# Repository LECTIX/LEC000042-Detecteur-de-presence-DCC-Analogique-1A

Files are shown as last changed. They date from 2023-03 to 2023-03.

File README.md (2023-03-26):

# LEC000042-Detecteur-de-presence-DCC-Analogique-1A
Fichiers sources pour le produit LEC000042

## Description du produit

### DCC (Digital)

En DCC, le détecteur d’occupation LEC000042 permet de détecter l’occupation d’un tronçon de voie et de déclencher de nombreux automatismes ou systèmes.
- Détecte tous les trains dans les **2 sens de marche**.
- Seuil de détection **ultrasensible et réglable**.
- **Relais double inverseur** pour y brancher n'importe quel système.
- Temporisation à la désactivation pour **éviter des réactivations intempestives**.
- **Possibilité de forcer** l'activation du relais via un bornier dédié.

### Analogique

Le détecteur d’occupation LEC000042 permet de détecter l’occupation d’un tronçon de voie et de déclencher de nombreux automatismes ou systèmes.
- Détecte tous les trains dans **1 seul sens de marche, à partir de 6 V**.
- Seuil de détection **ultrasensible et réglable**.
- **Relais double inverseur** pour y brancher n'importe quel système.
- Temporisation à la désactivation pour **éviter des réactivations intempestives**.
- **Possibilité de forcer** l'activation du relais via un bornier dédié.

## Utiliser les fichiers sources pour fabriquer le produit

Il n'est **pas nécessaire de savoir souder ou d'être bon en électronique** pour se procurer ce produit. Grâce aux fichiers sources publiés ici, vous pouvez être en mesure de faire fabriquer ce produit par un sous traitant.

### Faire fabriquer chez un sous traitant

Il est aujourd'hui possible de faire fabriquer à moindre cout des cartes électroniques. Nous recommendons [JLCPCB](https://jlcpcb.com/) si vous voulez aller au moins cher. Si vous préférez un acteur européen, [eurocircuits](https://www.eurocircuits.com/) est un des acteurs reconnus.

IMAGE ALT TEXT (http://www.youtube.com/watch?v=RXGGvsUtz0c "TUTO : faire fabriquer un produit LECTIX")

1. Télécherger les sources de ce produit en cliquant sur le bouton `Code`, puis `Download ZIP`.
1. Décompresser le dossier.
1. Les fichiers pour la fabrication se trouvent dans le répertoire `hardware/prod`.
1. Se connecter sur [https://cart.jlcpcb.com/quote](https://cart.jlcpcb.com/quote)
1. Cliquer sur le bouton `Add gerber file` et sélectionner le fichier `gerbers.zip`.
1. Sélectionnez la quantité de cartes que vous souhaitez dans le champs `PCB Qty`.
1. Laisser toutes les autres options par défaut, puis cliquez sur le toggle switch en face de `PCB Assembly`, et enfin sur le bouton `confirm`.
1. Une preview de la carte électronique sans les composants doit apparaitre. Cliquez sur `NEXT`.
1. Cliquez sur le bouton `Add BOM File`, puis sélectionnez le fichier `bom.csv`
1. Cliquez sur le bouton `Add CPL File`, puis sélectionnez le fichier `pos.csv`
1. **Vérifier que tous les composants sont en stock** et bien sélectionnés, puis cliquez sur `NEXT`.
1. Une preview de la carte avec ses composants apparait. Continuer le chemin en cliquant sur `NEXT`.
1. Le prix final apparait. Sélectionnez la catégorie du produit, puis cliquez sur `SAVE TO CART`.
1. Une fois sauvegardé dans votre panier, vous pouvez valider votre commande et choisir le moyen d'acheminement. Afin de ne pas avoir à se préoccuper des frais de douane, nous vous conseillons de choisir une méthode d'expédition DDP.

Vous receverez vos cartes sous 1 à 3 semaines. 

**Nous ne sommes en aucun cas responsables des cartes qui arriveraient défectueuses ou non fonctionnelles.**

### Modifications des fichiers sources

Installez kicad 6 (ou version supérieure), et ouvrez le fichier LEC000042.kicad_pro

### Regénérer les fichiers gerber, BOM, et position (Optionnel)

Peut se faire simplement en utilisant kikit :

```
cd hardware
docker run --rm -w /kikit -v $PWD:/kikit yaqwsx/kikit kikit fab jlcpcb --assembly --no-drc --schematic LEC000042.kicad_sch --field LCSC --corrections JLCPCB_CORRECTION --nametemplate LEC000042_{} LEC000042.kicad_pcb prod/

```
## Notices

### DCC

[Manuel FR](docs/dcc/manual_fr.pdf)

[Manuel EN](docs/dcc/manual_en.pdf)

### Analogique

[Manuel FR](docs/analogique/manual_fr.pdf)

## License
Tous nos fichiers sont plubliés sous la license CERN Open Hardware Licence Version 2 - Strongly Reciprocal

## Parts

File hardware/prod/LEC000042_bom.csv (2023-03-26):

Comment | Designator | Footprint | LCSC
100uF | C1,C3 | 0_capacitors:CP_Elec_6.3x5.8 | C249982
100nF | C2,C5 | Capacitor_SMD:C_0603_1608Metric | C14663
10n | C6 | Capacitor_SMD:C_0603_1608Metric | C57112
10uF | C7,C8 | Capacitor_Tantalum_SMD:CP_EIA-3216-18_Kemet-A | C7171
MB10S | D1 | Package_TO_SOT_SMD:TO-269AA | C2488
D | D2,D3,D4,D5,D8,D9 | Diode_SMD:D_SMA | C95872
D_Schottky_Small | D6 | Diode_SMD:D_SMA | C22452
LED | D7 | LED_SMD:LED_0603_1608Metric | C72043
FORCE_ACTIVATION | J1 | 0_connectors:TerminalBlock_bornier-2_P5.08mm-blue | C430621
TRACKS_OUT | J2 | 0_connectors:TerminalBlock_bornier-2_P5.08mm-blue | C430621
TRACKS_IN | J3 | 0_connectors:TerminalBlock_bornier-2_P5.08mm-green | C395849
CONTACT_1 | J5 | 0_connectors:TerminalBlock_bornier-3_P5.08mm-blue | C430620
CONTACT_2 | J6 | 0_connectors:TerminalBlock_bornier-3_P5.08mm-blue | C430620
HK19F-5V | K1 | 0_relays:Relay_DPDT_HK19F | C54512
47uH | L1 | Inductor_SMD:L_12x12mm_H6mm | C169398
S8050 | Q1 | Package_TO_SOT_SMD:SOT-23 | C2146
27 | R1 | Resistor_SMD:R_0603_1608Metric | C25190
3k | R2 | Resistor_SMD:R_0603_1608Metric | C4211
1k | R3,R5,R6 | Resistor_SMD:R_0603_1608Metric | C21190
180k | R4 | Resistor_SMD:R_0603_1608Metric | C22827
10k | R7 | Resistor_SMD:R_0603_1608Metric | C25804
500k | RV1 | 0_potentiometers:BOURNS-3362P_pot | C125021
NE555 | U1 | Package_SO:SOIC-8_3.9x4.9mm_P1.27mm | C7593
CYPC817 | U2 | Package_DIP:SMDIP-4_W9.53mm_Clearance8mm | C385060
XL1509-ADJE1 | U3 | Package_SO:SOP-8_3.76x4.96mm_P1.27mm | C74192

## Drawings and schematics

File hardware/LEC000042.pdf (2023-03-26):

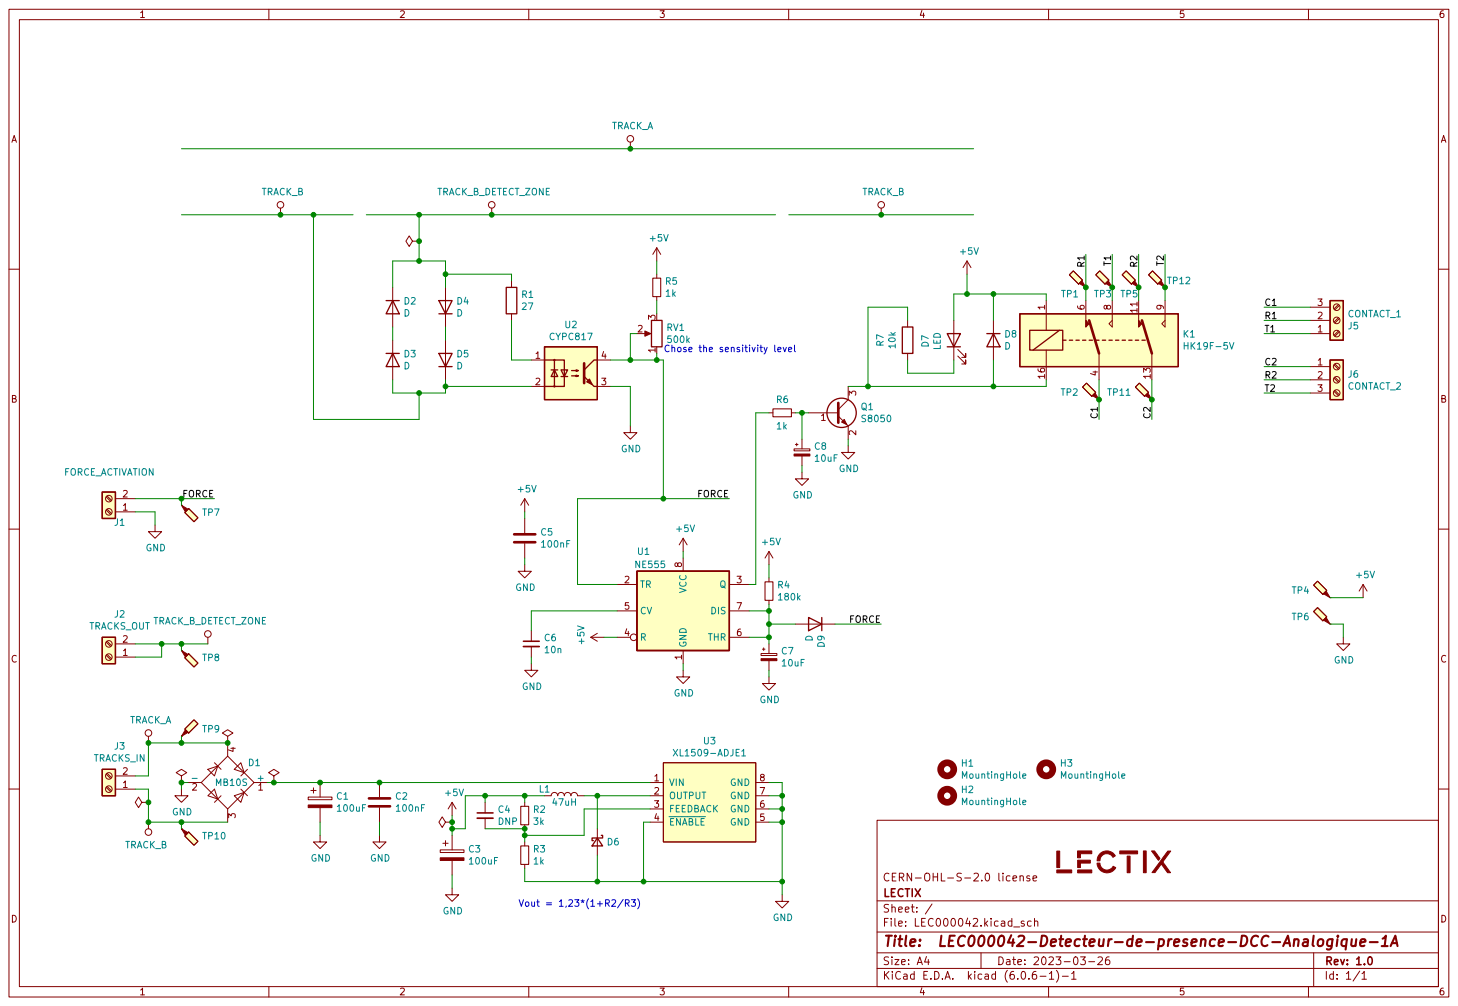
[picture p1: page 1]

9 K1HK19F-5V D6 VIN 1 OUTPUT 2 FEEDBACK 3 ~{ENABLE} 4 GND 5 GND 6 GND 7 GND 8 U3 XL1509-ADJE1 R2

File: LEC000042.kicad_sch Sheet: / LECTIX CERN-OHL-S-2.0 license

Id: 1/1 Title: LEC000042-Detecteur-de-presence-DCC-Analogique-1A

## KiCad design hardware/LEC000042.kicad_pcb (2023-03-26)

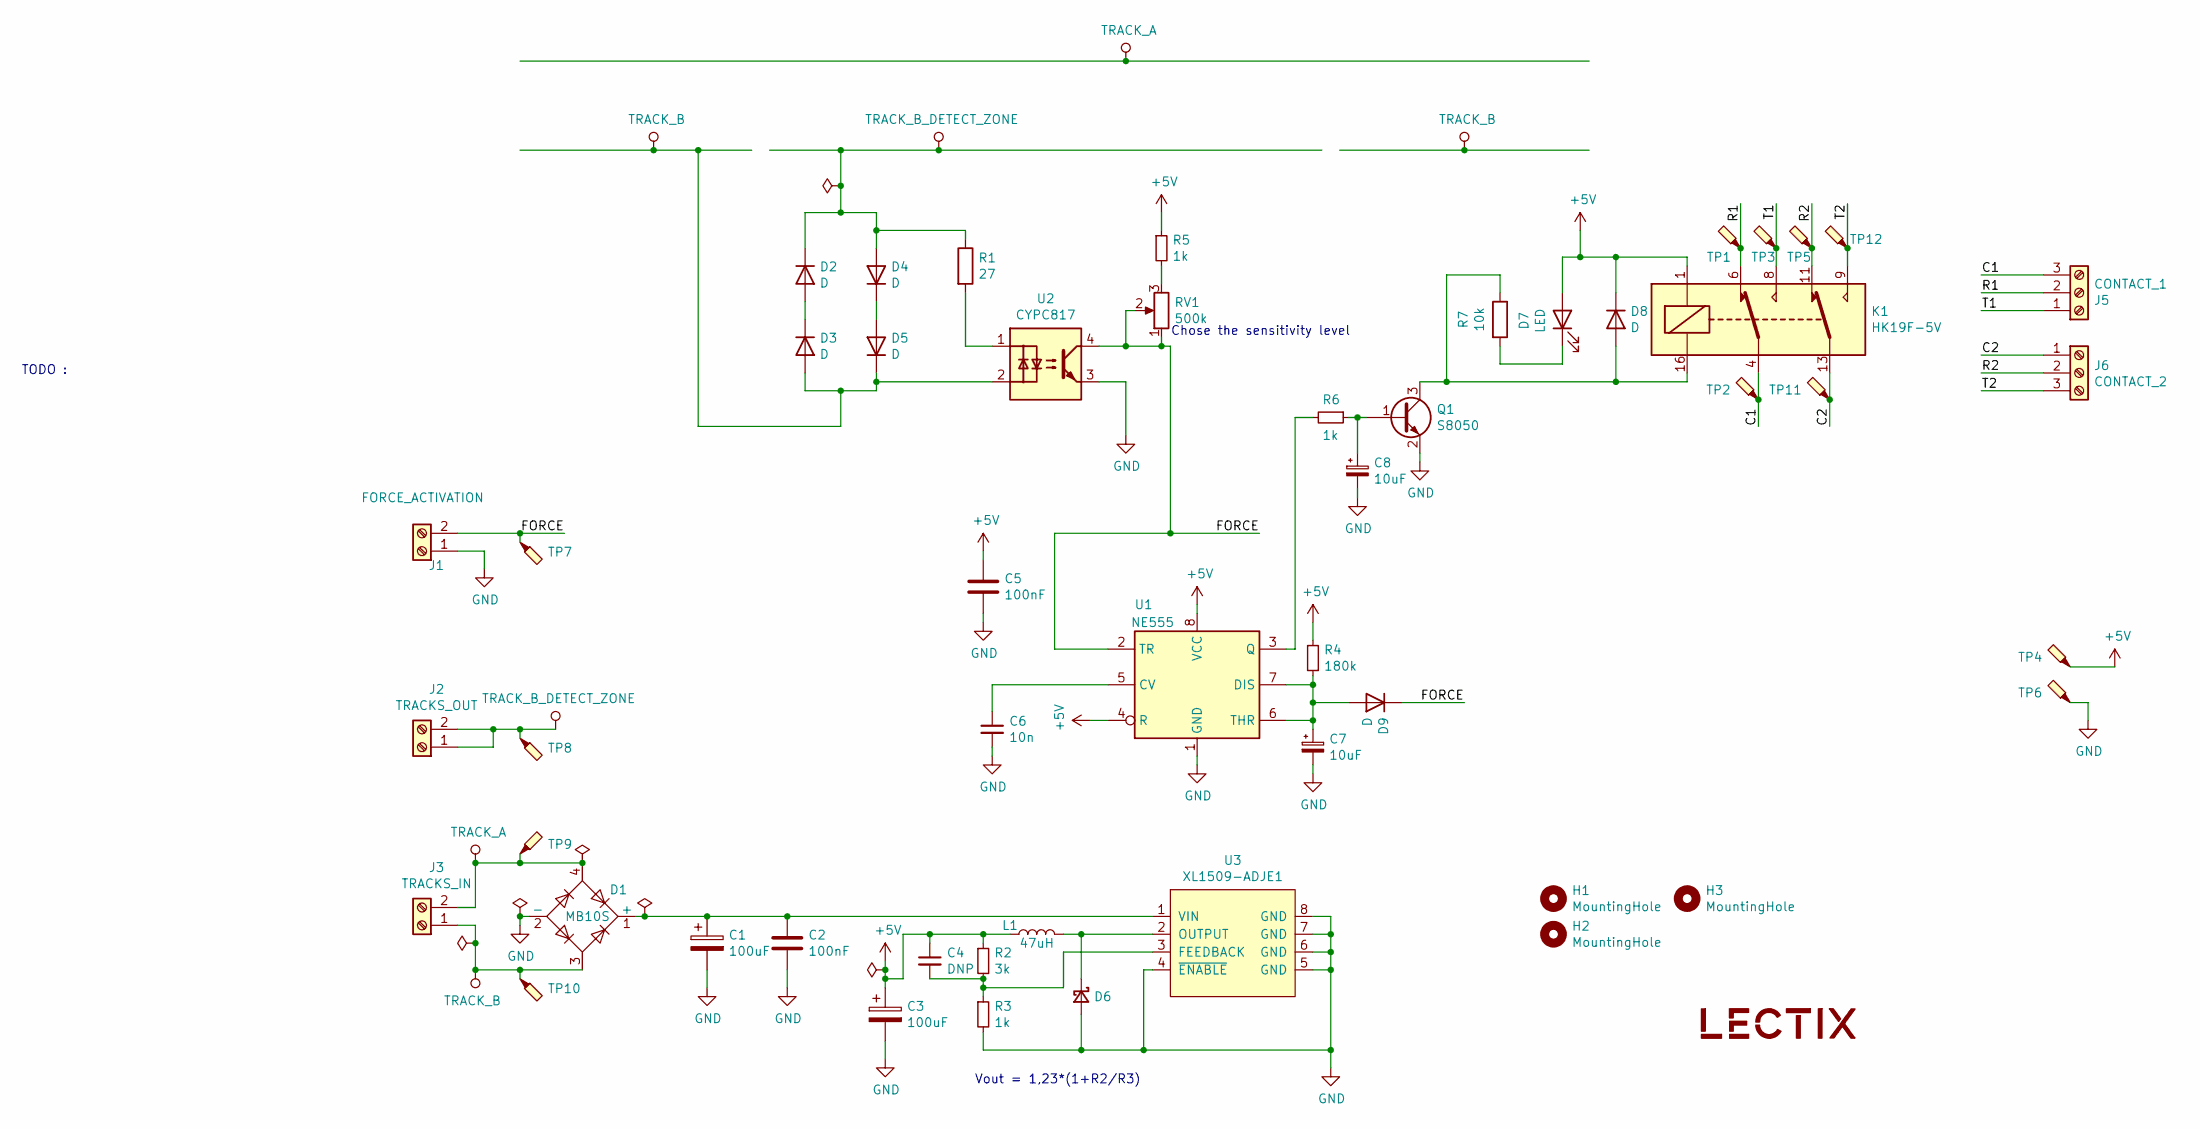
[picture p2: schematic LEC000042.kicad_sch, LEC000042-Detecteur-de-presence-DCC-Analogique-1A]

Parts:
C1, C3: 100uF; CP_Elec_6.3x5.8; MPN VZT101M1VTR-0606; LCSC C249982
C2, C5: 100nF; C_0603_1608Metric; MPN CC0603KRX7R9BB104; LCSC C14663
C4: DNP; C_0603_1608Metric; MPN DNP; LCSC DNP
C6: 10n; C_0603_1608Metric; MPN 0603B103K500NT; LCSC C57112
C7, C8: 10uF; CP_EIA-3216-18_Kemet-A; MPN TAJA106K016RNJ; LCSC C7171
D1: MB10S; TO-269AA; MPN MB10S; LCSC C2488
D2, D3, D4, D5, D8, D9: D; D_SMA; MPN M7; LCSC C95872
D6: D_Schottky_Small; D_SMA; MPN SS54; LCSC C22452
D7: LED; LED_0603_1608Metric; MPN 19-217/GHC-YR1S2/3T; LCSC C72043
H1, H2, H3: MountingHole; MountingHole_3.2mm_M3; MPN DNP; LCSC DNP
J1: FORCE_ACTIVATION; TerminalBlock_bornier-2_P5.08mm-blue; MPN DB301V-5.0-2P-BU-P; LCSC C430621
J2: TRACKS_OUT; TerminalBlock_bornier-2_P5.08mm-blue; MPN DB301V-5.0-2P-BU-P; LCSC C430621
J3: TRACKS_IN; TerminalBlock_bornier-2_P5.08mm-green; MPN DB126V-5.0-2P-GN; LCSC C395849
J5: CONTACT_1; TerminalBlock_bornier-3_P5.08mm-blue; MPN DB301V-5.0-3P-BU-P; LCSC C430620
J6: CONTACT_2; TerminalBlock_bornier-3_P5.08mm-blue; MPN DB301V-5.0-3P-BU-P; LCSC C430620
K1: HK19F-5V; Relay_DPDT_HK19F; MPN HK19F-DC5V-SHG-Y; LCSC C54512
L1: 47uH; L_12x12mm_H6mm; MPN SWRB1204S-470MT; LCSC C169398
LOGO1: logo_lectix_25mm; Logo_10mm; MPN DNP; LCSC DNP
Q1: S8050; SOT-23; MPN S8050; LCSC C2146
R1: 27; R_0603_1608Metric; MPN 0603WAF270JT5E; LCSC C25190
R2: 3k; R_0603_1608Metric; MPN 0603WAF3001T5E; LCSC C4211
R3, R5, R6: 1k; R_0603_1608Metric; MPN 0603WAF1001T5E; LCSC C21190
R4: 180k; R_0603_1608Metric; MPN 0603WAF1803T5E; LCSC C22827
R7: 10k; R_0603_1608Metric; MPN 0603WAF1002T5E; LCSC C25804
RV1: 500k; BOURNS-3362P_pot; MPN 3362P-1-504; LCSC C125021
TP1, TP2, TP3, TP4, TP5, TP6, TP7, TP8, TP9, TP10, TP11, TP12: TestPoint_Probe; TestPoint_Pad_D1.5mm; MPN DNP; LCSC DNP
U1: NE555; SOIC-8_3.9x4.9mm_P1.27mm; MPN NE555; LCSC C7593
U2: CYPC817; SMDIP-4_W9.53mm_Clearance8mm; MPN CYPC817(B-TP2); LCSC C385060
U3: XL1509-ADJE1; SOP-8_3.76x4.96mm_P1.27mm; MPN XL1509-ADJE1; LCSC C74192

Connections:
+5V: C3.1, C4.1, C5.1, D7.2 (A), D8.1 (K), K1.1, L1.1, R2.1, R4.1, R5.1, TP4.1, U1.4 (R), U1.8 (VCC)
/C1: J5.3, K1.4, TP2.1
/C2: J6.1, K1.13, TP11.1
/FORCE: D9.1 (K), J1.2, RV1.1, RV1.2, TP7.1, U1.2 (TR), U2.4
/R1: J5.2, K1.6, TP1.1
/R2: J6.2, K1.11, TP5.1
/T1: J5.1, K1.8, TP3.1
/T2: J6.3, K1.9, TP12.1
GND: C1.2, C2.2, C3.2, C5.2, C6.2, C7.2, C8.2, D1.2 (-), D6.2 (A), J1.1, Q1.2 (E), R3.2, TP6.1, U1.1 (GND), U2.3, U3.4 (~ENABLE), U3.5 (GND), U3.6 (GND), U3.7 (GND), U3.8 (GND)
unnamed: C1.1, C2.1, D1.1 (+), U3.1 (VIN)
unnamed: C4.2, R2.2, R3.1, U3.3 (FEEDBACK)
unnamed: C6.1, U1.5 (CV)
unnamed: C7.1, D9.2 (A), R4.2, U1.6 (THR), U1.7 (DIS)
unnamed: C8.1, Q1.1 (B), R6.1
unnamed: D2.2 (A), D3.1 (K)
unnamed: D4.1 (K), D5.2 (A)
unnamed: D6.1 (K), L1.2, U3.2 (OUTPUT)
unnamed: D7.1 (K), R7.2
unnamed: D8.2 (A), K1.16, Q1.3 (C), R7.1
unnamed: R1.2, U2.1
unnamed: R5.2, RV1.3
unnamed: R6.2, U1.3 (Q)
TRACK_A: D1.4, J3.2, TP9.1
TRACK_B: D1.3, D3.2 (A), D5.1 (K), J3.1, TP10.1, U2.2
TRACK_B_DETECT_ZONE: D2.1 (K), D4.2 (A), J2.1, J2.2, R1.1, TP8.1

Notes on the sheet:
TODO :
Vout = 1,23*(1+R2/R3)
Chose the sensitivity level

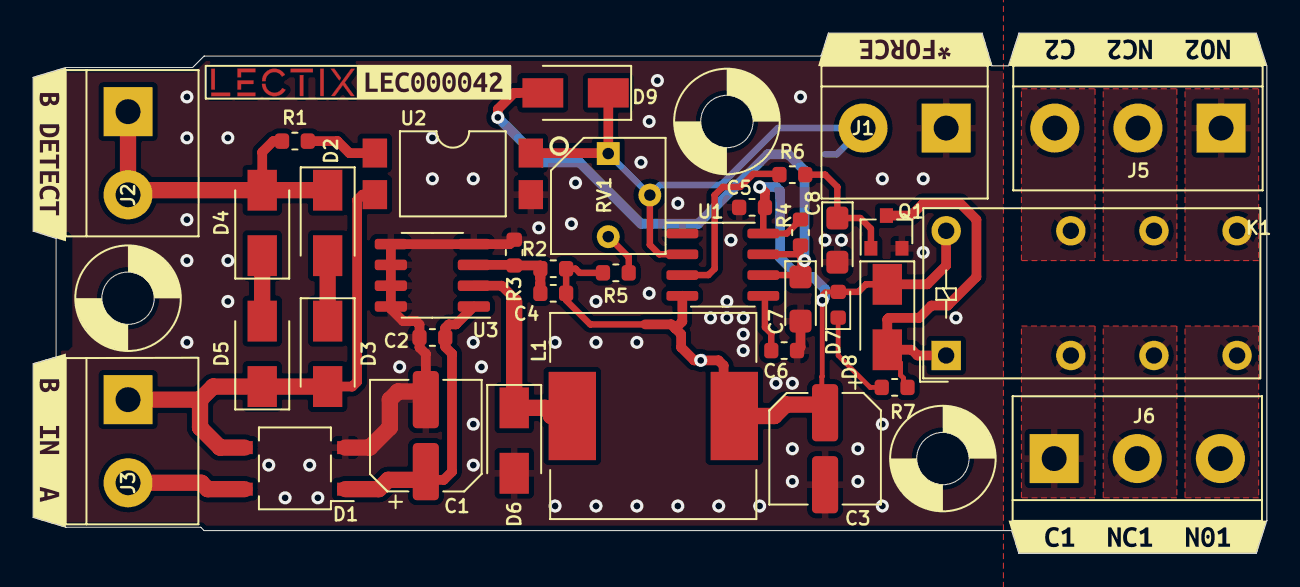
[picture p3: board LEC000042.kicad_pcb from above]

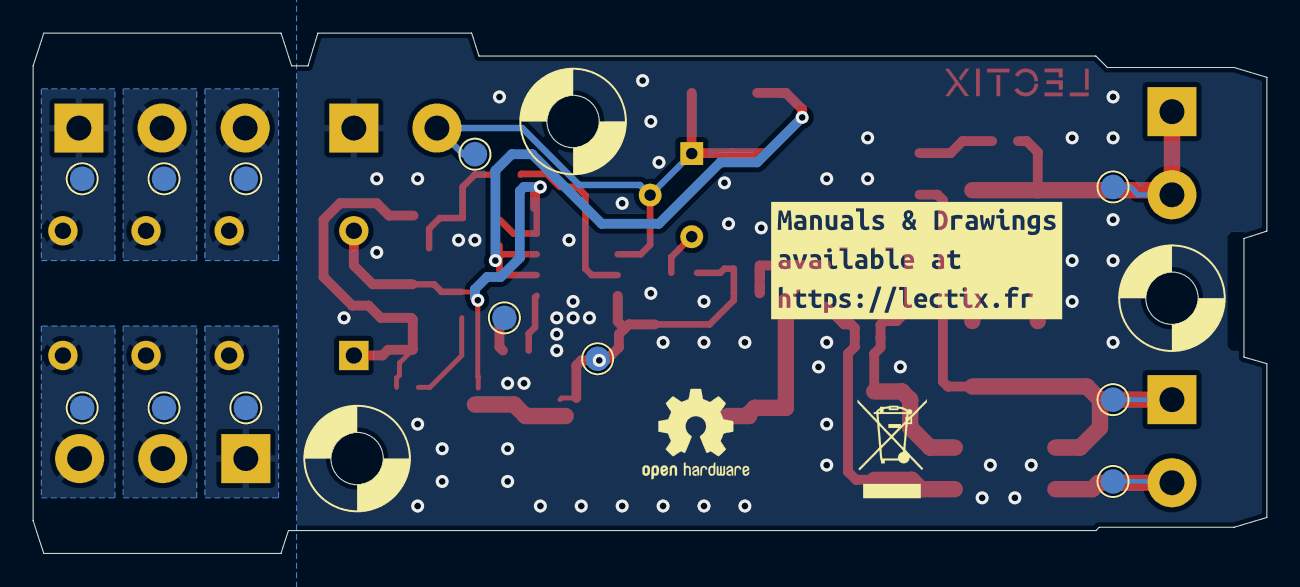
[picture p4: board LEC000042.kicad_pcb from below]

Board: 2 copper layers, 75.4 x 31.8 mm, 59 parts (13 on the bottom side), 25 nets.

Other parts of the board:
kibuzzard-624D4A0B: G***; kibuzzard-624D4A0B
kibuzzard-624D4A7D: G***; kibuzzard-624D4A7D
kibuzzard-624D4ACF: G***; kibuzzard-624D4ACF
kibuzzard-624D4AF8: G***; kibuzzard-624D4AF8
kibuzzard-624D4BCC: G***; kibuzzard-624D4BCC
kibuzzard-624D4BDE: G***; kibuzzard-624D4BDE
kibuzzard-624D5053: G***; kibuzzard-624D5053

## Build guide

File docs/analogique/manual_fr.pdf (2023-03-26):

# Détecteur d’occupation (Analogique)

### LEC000042

☞ Attention : ce manuel décrit l’utilisation du module LEC000042 pour une installation en analogique uniquement. Pour une utilisation en DCC, rendez vous sur notre site web. (https://lectix.fr/)

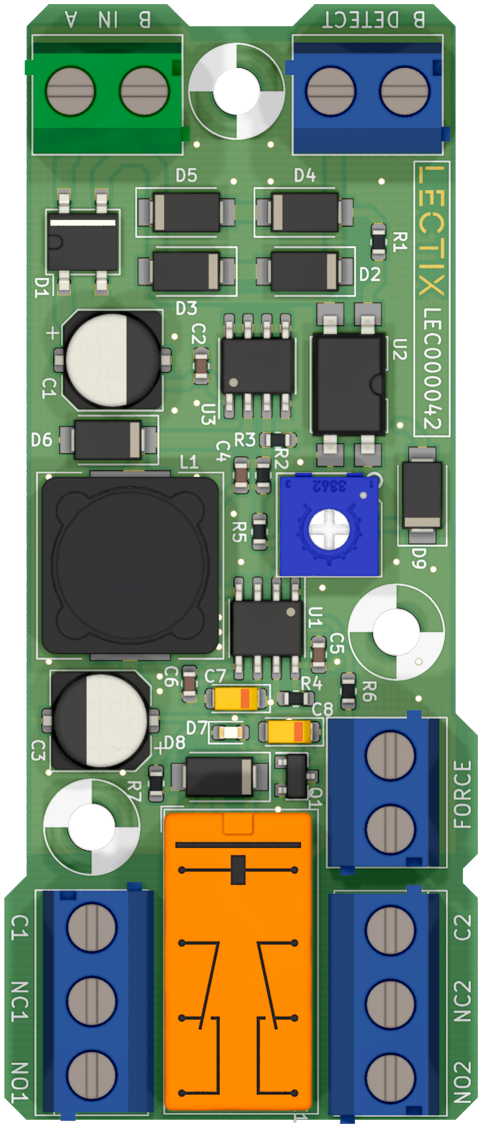
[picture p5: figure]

## 1 Caractéristiques

- Capable de détecter tous les trains dans 1 seul sens de marche, à partir de 6 V.
- Réglage possible du seuil de détection (de 0.2 mA à 2 mA).
- Possède un relais à 2 contacts inverseurs indépendants pour y brancher n’importe quel système.
- Témoin lumineux d’activation.
- Possibilité de forcer l’activation du module par un actionneur externe.
- Temporisation à la désactivation pour éviter des réactivations intempestives.

## 2 Applications

- Cantonnement.
- Déclenchement d’un bruitage.
- Automatismes (passage à niveau, ...).
- Gestion de la signalisation.

## 3 Specifications technique

Specification | Valeur | Unité
Seuil de détection | 0.2 - 2 | mA
Consommation (inactif @20V) (actif @20V) | 3.5 17 | mA mA
Pouvoir de coupure du relais | 1A 125V AC 2A 30V DC | -
Courant max supporté | 1 | A
Tension de fonctionnement | 6 à 20 | V DC

Table 1: Spécifications

LEC000042 - Détecteur d’occupation (Analogique) rev 4.2.1 | 1

## 4 Dimensions

Le module dispose de trois trous de fixation permettant de faire passer des vis de 3 mm.

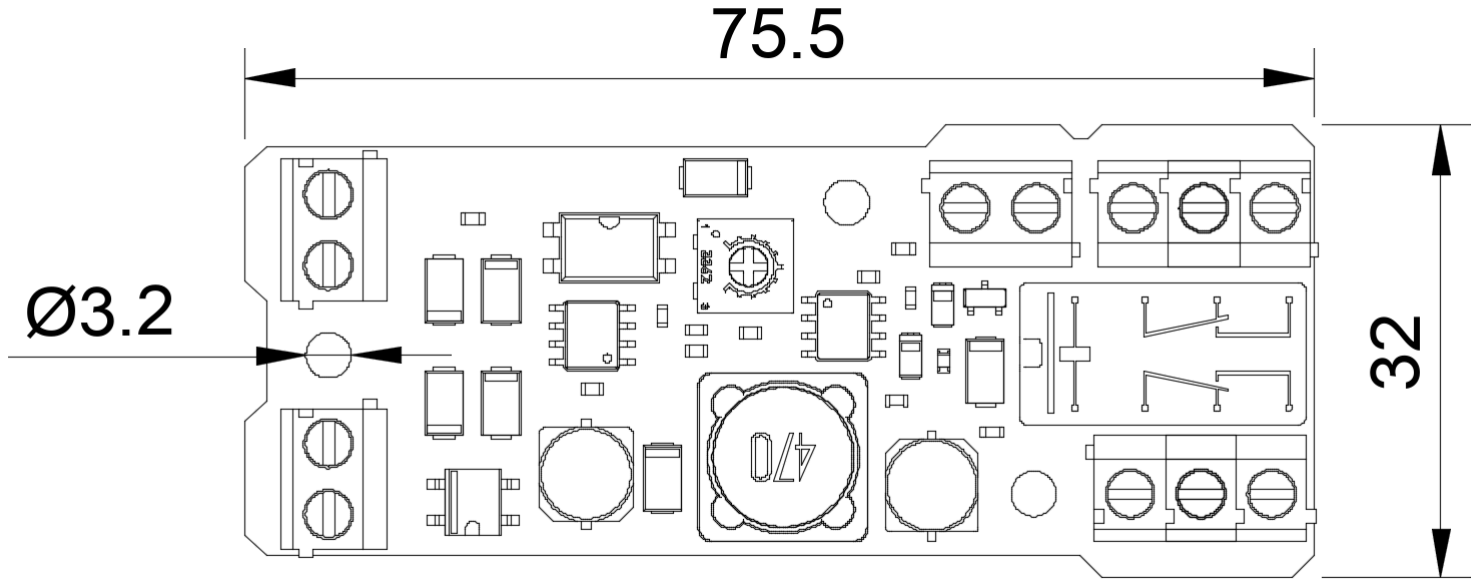
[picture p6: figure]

Figure 1: Dimensions du module (toutes les côtes sont données en mm).

## 5 Utilisation

Le détecteur d’occupation LEC000042 permet de détecter l’occupation d’un tronçon de voie et de déclencher de nombreux automatismes ou systèmes. La sensibilité réglable du module vous permettra de détecter sans aucun soucis vos locomotives, wagons ayant de l’éclairage, ou encore tous les essieux graphités de votre matériel roulant.

### 5.1 Installation et câblage du module

☞ Remarque : pour un fonctionnement optimal et sans danger, le câblage de ce module doit se faire avec un fil possédant une section minimale de 0.2mm²

Le module doit être câblé tel que sur la figure 2. A noter qu’il est important de respecter l’association d’un rail à une lettre (A = rail droit dans le sens de marche, B = rail gauche dans le sens de marche).

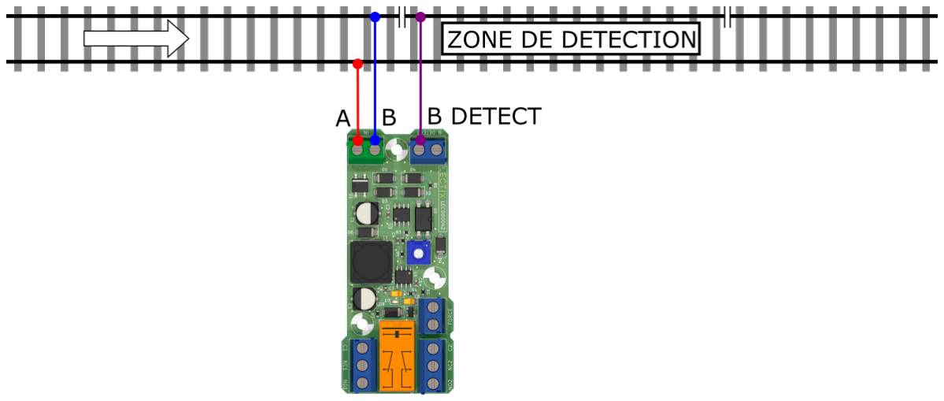
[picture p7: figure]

Figure 2: Schéma de câblage du module.

L’installation du système est simple et rapide :

1. Isolez le rail gauche de votre zone de détection.
2. Branchez les rails d’alimentation, ou directement des fils provenant de votre alimentation traction sur le bornier vert (bornes A et B, A = rail droit dans le sens de marche, B = rail gauche dans le sens de marche).
3. Branchez le rail gauche isolé sur une des 2 bornes "B DETECT".
4. Testez et profitez de toutes les possibilités offertes par les contacts inverseurs du détecteur.
5. Fixez le module à l’aide de vis ou de colle chaude.

Une fois les branchements de la figure 2 effectués, vous pouvez brancher un système ou un automatisme à activer grâce aux contacts inverseurs du relais (Cf. figure 3). Vous trouverez des exemples d’utilisation à la fin de ce manuel.

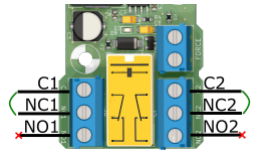
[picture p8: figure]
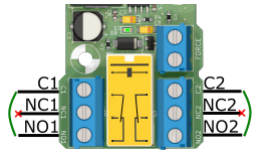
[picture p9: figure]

(a) Relais désactivé. | (b) Relais activé.

Figure 3: Description des contacts inverseurs du relais.

5.2 (optionnel) Forcer l’activation du relais.

Certains systèmes, tels que la gestion d’un arrêt en gare, peuvent nécessiter le besoin de forcer l’activation du relais. Pour ce faire, il vous suffira de relier les deux bornes "FORCE" par un interrupteur (Cf. figure 4).

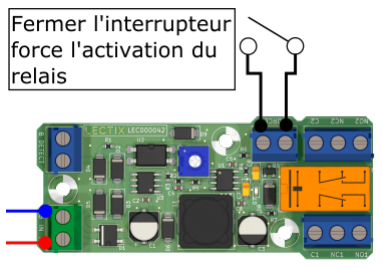
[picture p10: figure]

Figure 4: Forçage de l’activation du relais.

5.3 (optionnel) Régler la sensibilité de la détection.

Le module arrive pré-réglé sur une sensibilité de détection standard qui devrait permettre de détecter toute locomotive, à partir de 6V. Si jamais le niveau de détection ne vous satisfait pas, il est possible de le régler comme indiqué sur la figure 5.

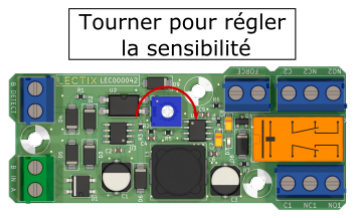
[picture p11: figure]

Figure 5: Réglage du seuil de détection.

Pour diminuer la sensibilité, tourner le potentiomètre dans le sens des aiguilles d’une montre. Pour augmenter la sensibilité, tourner le potentiomètre dans le sens inverse des aiguilles d’une montre.

☞ Note : Le potentiomètre est très fragile. NE jamais forcer dessus pour ne pas détériorer ou rendre inopérable le module.

### 5.4 Exemples d’utilisation

Les contacts inverseur du relais du module permettent une utilisation très générique. Voici quelques exemples d’utilisation.

5.4.1 Branchement d’un feu bicolore.

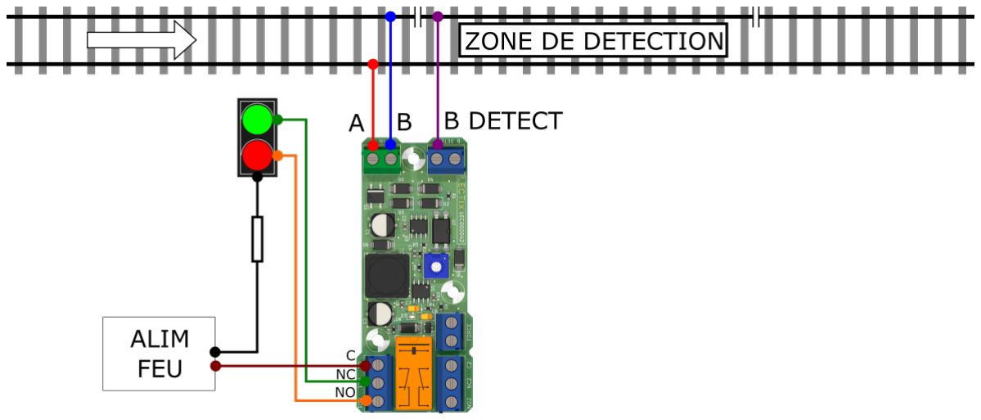
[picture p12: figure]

Figure 6: Branchement d’un feu bicolore.

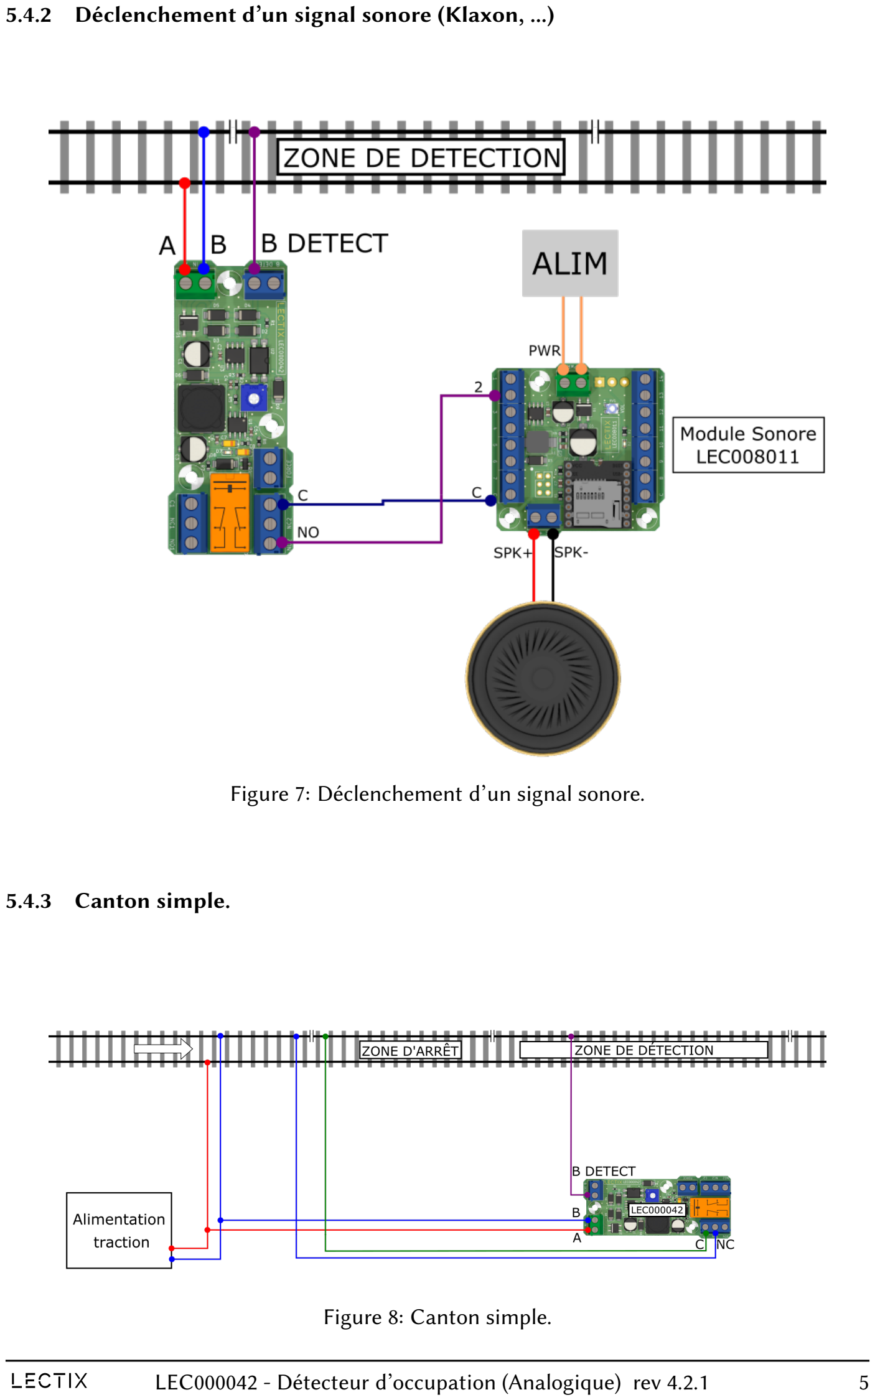
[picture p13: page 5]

### 5.4.2 Déclenchement d’un signal sonore (Klaxon, ...)

Figure 7: Déclenchement d’un signal sonore.

5.4.3 Canton simple.

Figure 8: Canton simple.

5.4.4 Cantons successifs.

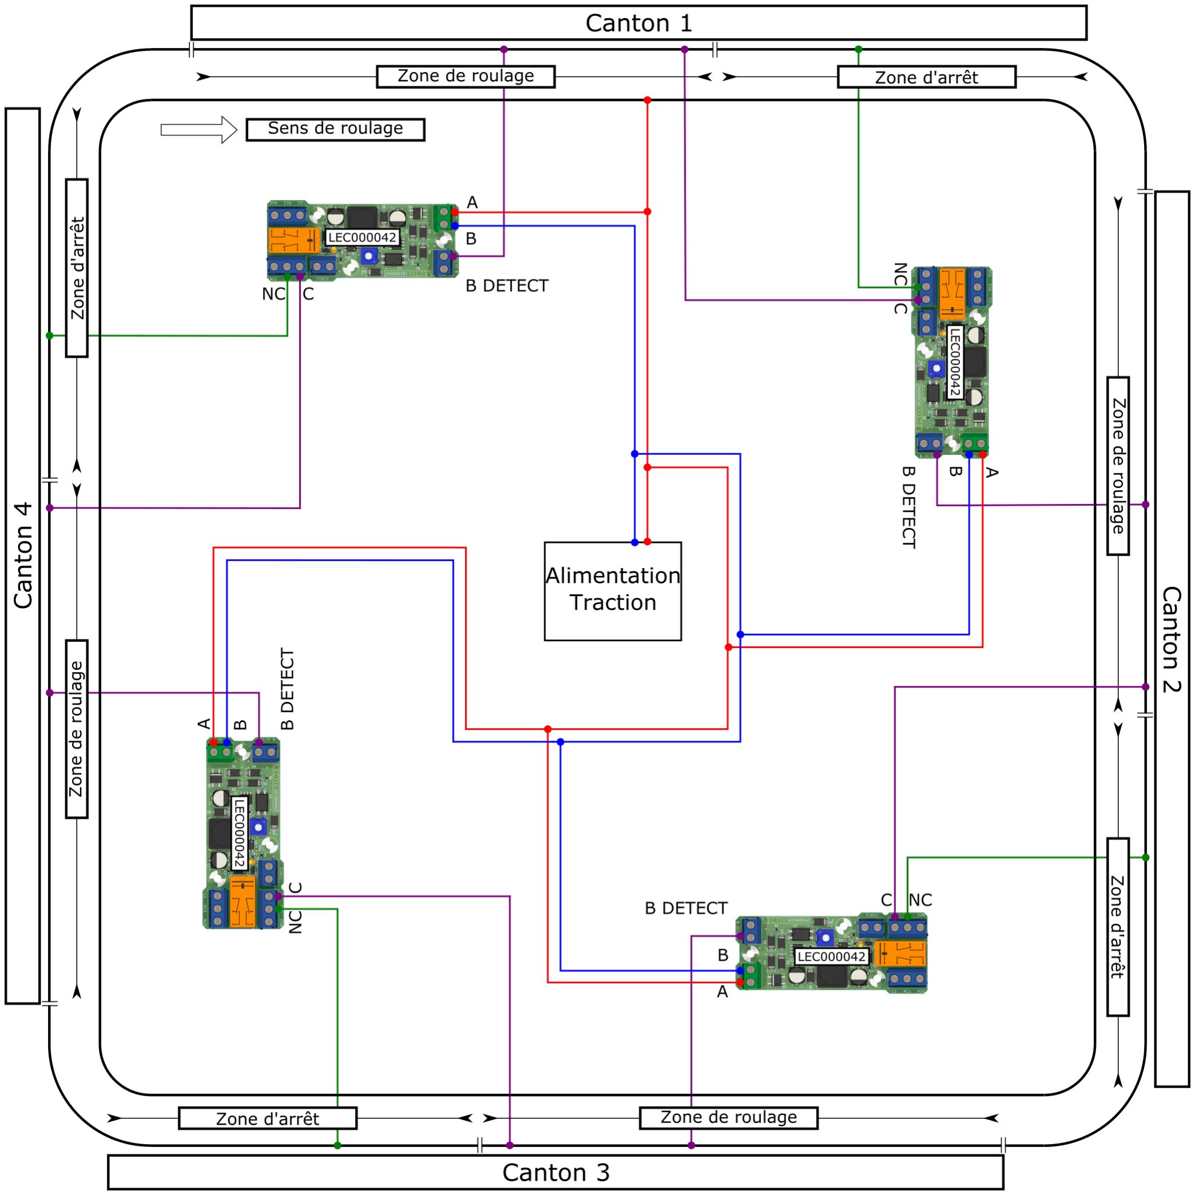
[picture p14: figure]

Figure 9: Cantons successifs.

## 6 Contact et SAV

Pour tout renseignement, veuillez vous adresser à contact@lectix.fr.

## Revision History

Revision Date | Author(s) | Description
4.2.0 | 11.12.21 TFC | Adaptation du manuel depuis LEC000041
4.2.1 | 10.07.22 TFC | Correction d’une coquille dans les figures 6 et 7.

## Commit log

2023-03-26 Add source files
    [LEC000042.kicad_pcb, LEC000042.kicad_sch]
2023-03-26 Add prod files
    [LEC000042-CmtUser.gbr, LEC000042-CuBottom.gbl, LEC000042-CuTop.gtl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]
2023-03-26 Add pdf schematic file
    [LEC000042.kicad_sch]
